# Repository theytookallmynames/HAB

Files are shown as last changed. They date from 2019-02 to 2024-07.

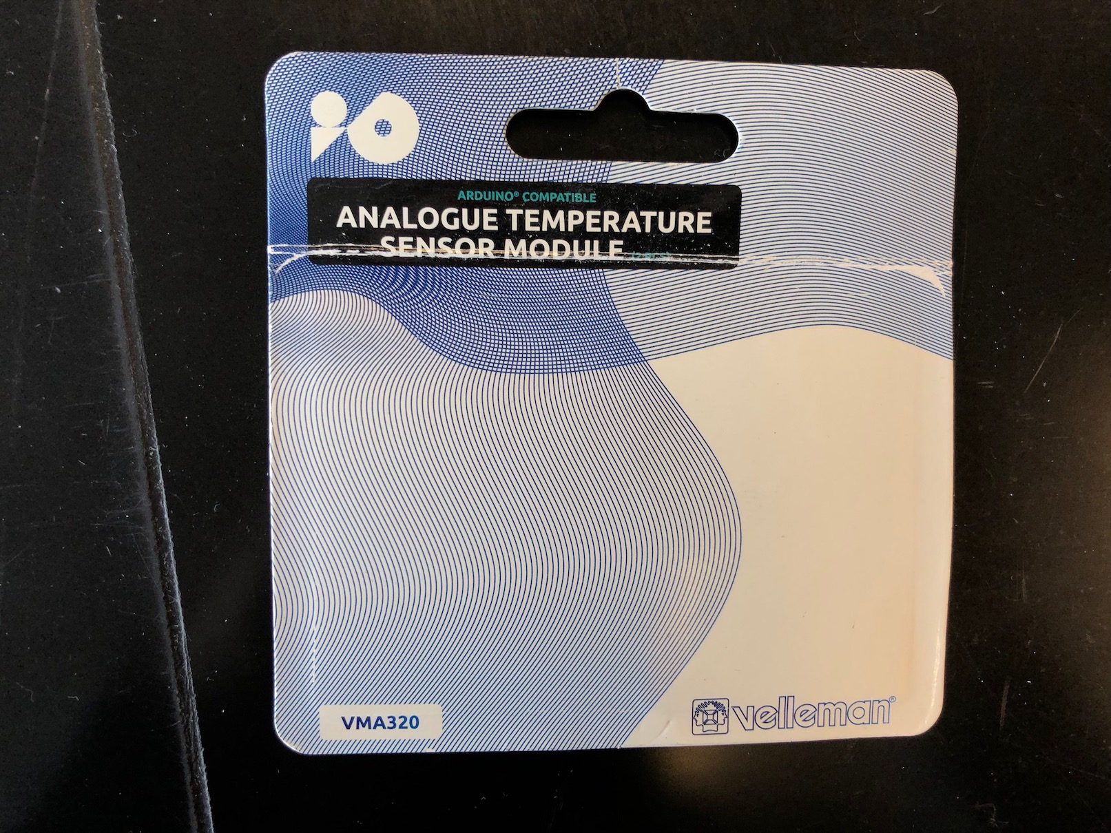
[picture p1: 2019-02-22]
docs/datasheets/temp sensors/thermistor package front.jpeg

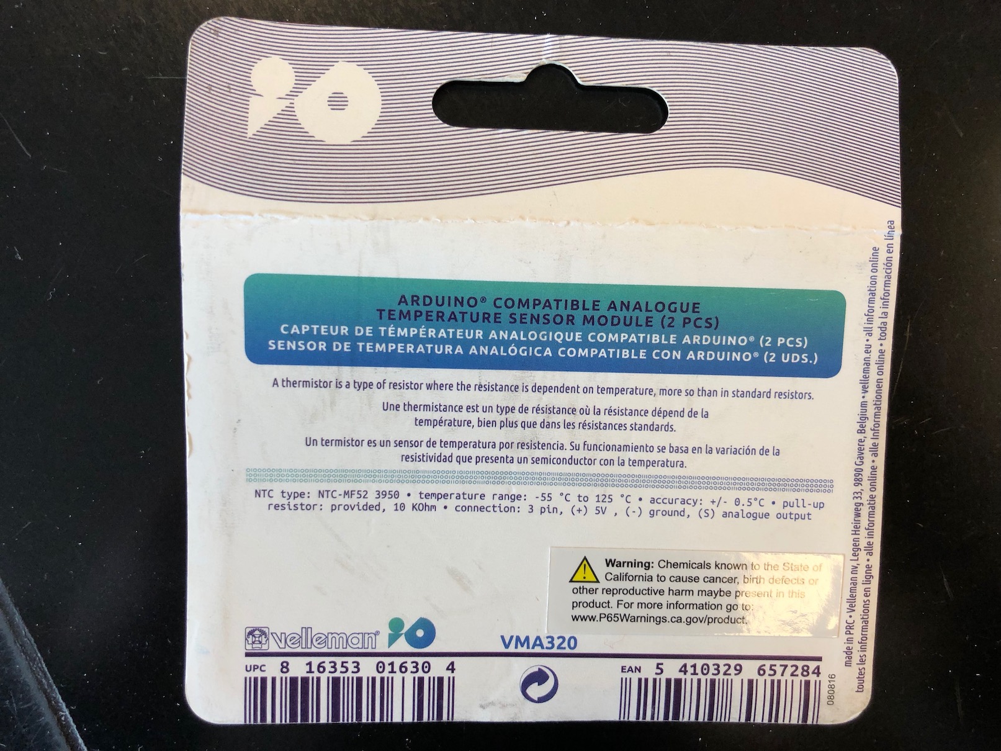
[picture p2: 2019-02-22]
docs/datasheets/temp sensors/thermistor package rear.jpeg

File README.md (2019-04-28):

# HAB
High altitude balloon project for Bergen's 2018 STEM program

## Setting up your development environment

1. Clone this repo.
2. Install the Arduino IDE: https://www.arduino.cc/en/main/software
3. Open the `HAB` directory in the repo in the IDE
4. Follow [these instructions](https://learn.adafruit.com/adafruit-feather-32u4-basic-proto/arduino-ide-setup) to install the "Adafruit AVR Boards" package in the IDE, and then set the board for the sketch to "Adafruit Feather M0" under the Tools > Boards menu.

You may need to install some additional libraries. To do that, go to the Tools menu in the Arduino IDE, search for the missing libraries, and hit the install button.

## Building the code

In the Arduino IDE, hit the checkmark button at the top of the window (or select Verify/Compile in the Sketch menu). This will make sure the code compiles correctly and will give some information at the bottom of the screen such as how much storage the compiled binary will take up on the device, and how much dynamic memory will be available for the program after global variables are taken into account.

## Installing on the arduino

In the Arduino IDE, press the button with the arrow (next to the button with the checkmark). If the code verifies properly, it will get uploaded to the Arduino and the Arduino will restart with the new code.

## Hardware

See the docs folder for datasheets.

### Board

Adafruit Feather M0 Adalogger

https://learn.adafruit.com/adafruit-feather-m0-adalogger/overview

### Sensors

#### Temperature sensor

Velleman VMA320 analog temperature sensor module

#### Pressure sensor

Honeywell HSCRNN1.6BA2A3

#### GPS receiver

Byonics GPS5HAOEM module
NaviSys GM-401 SiRFstarIV chip

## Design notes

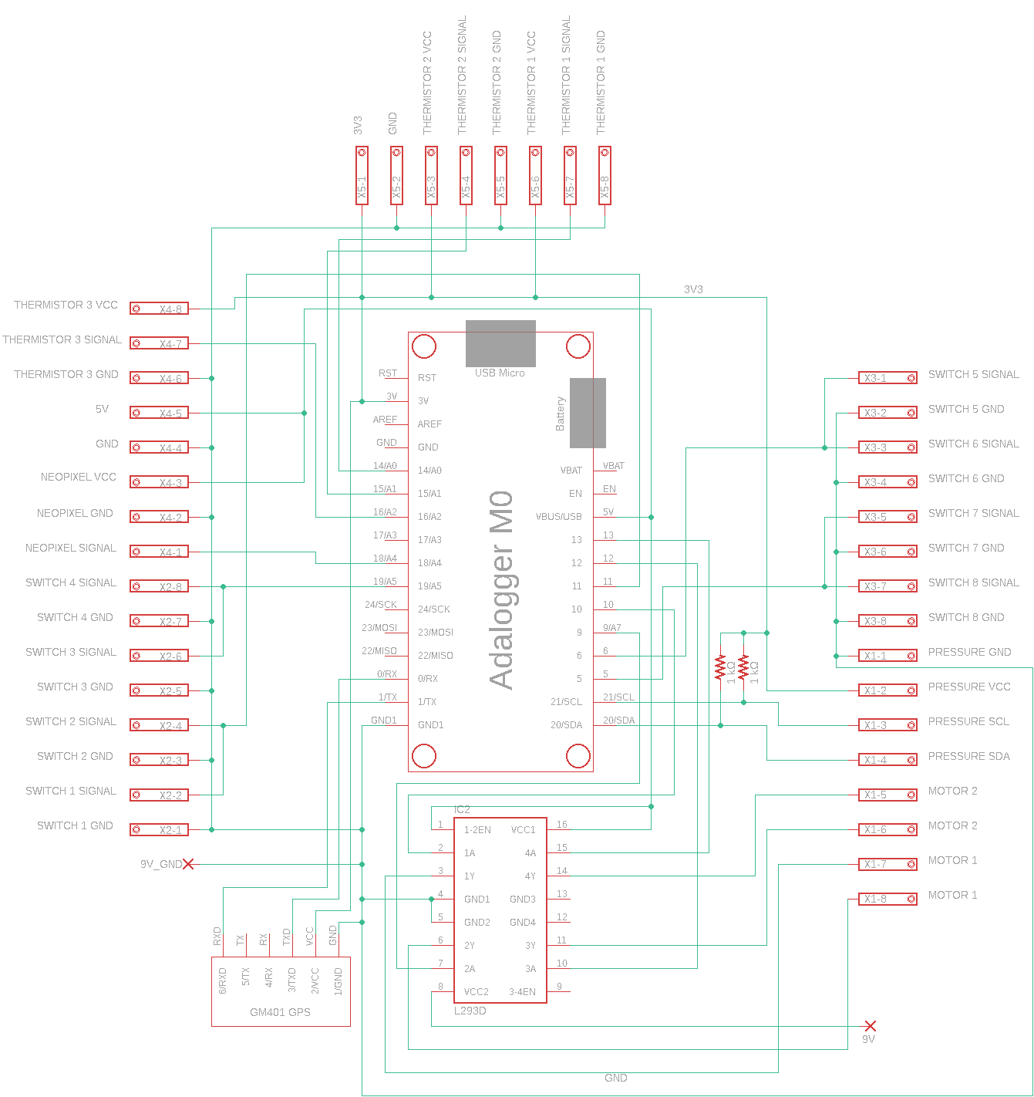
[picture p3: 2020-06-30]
docs/schematic v4.png

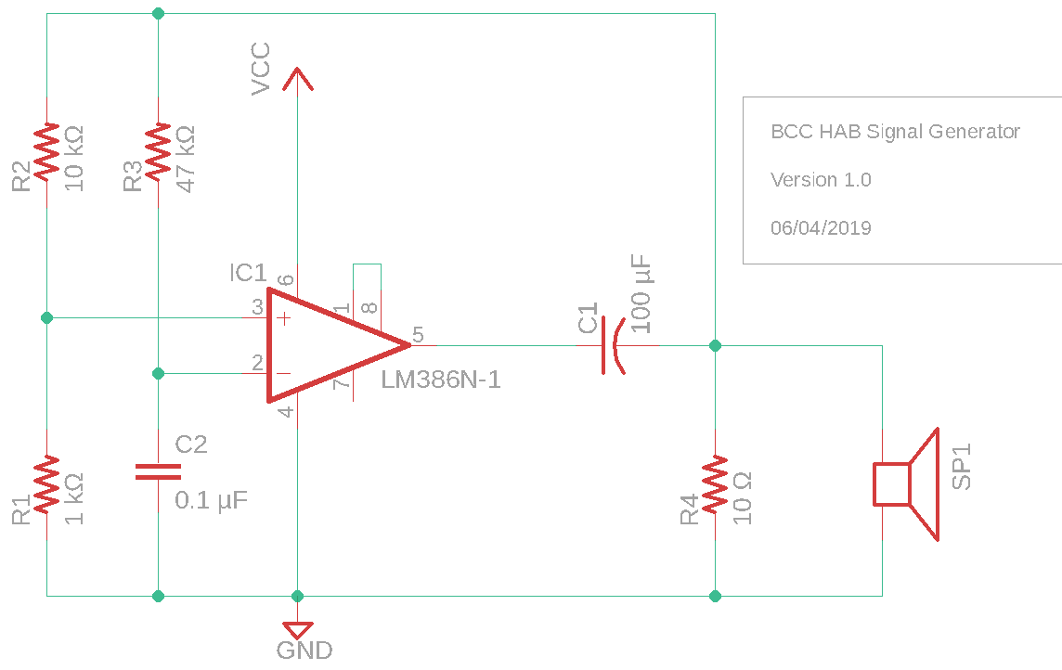
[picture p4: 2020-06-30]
docs/tone generator schematic v1.png

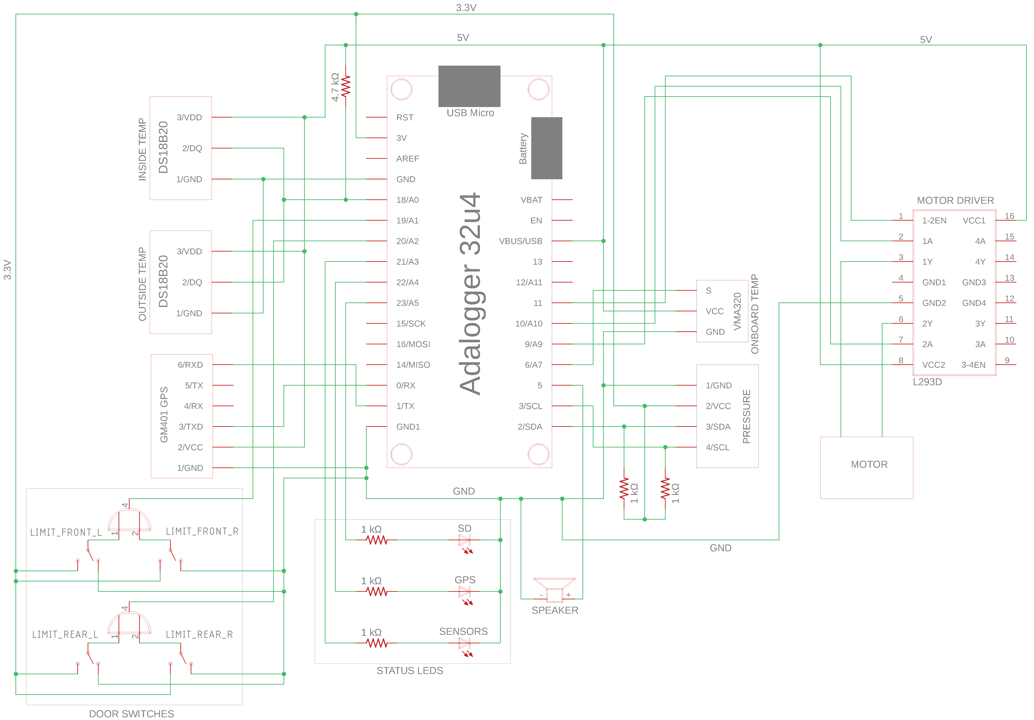
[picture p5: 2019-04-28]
docs/schematic v1.png

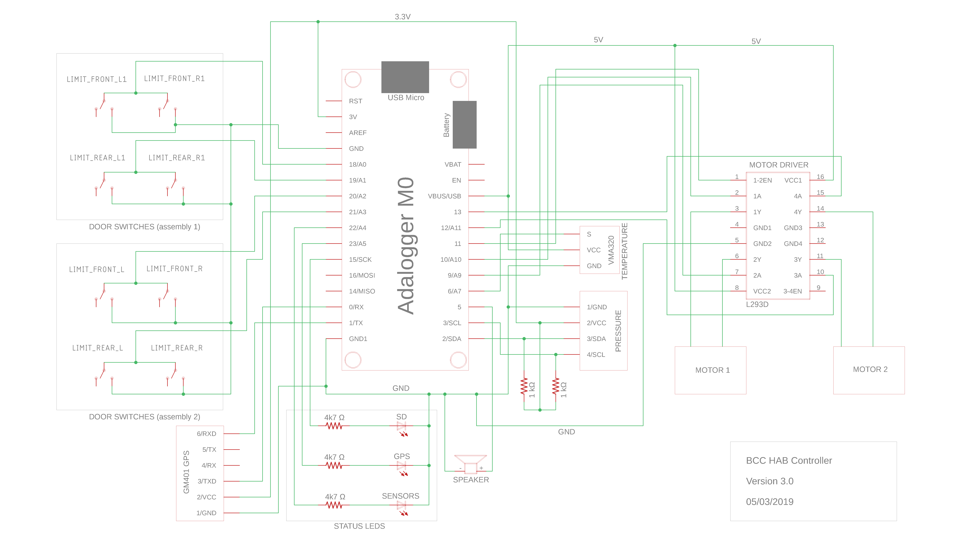
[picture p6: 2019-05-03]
docs/schematic v3.png

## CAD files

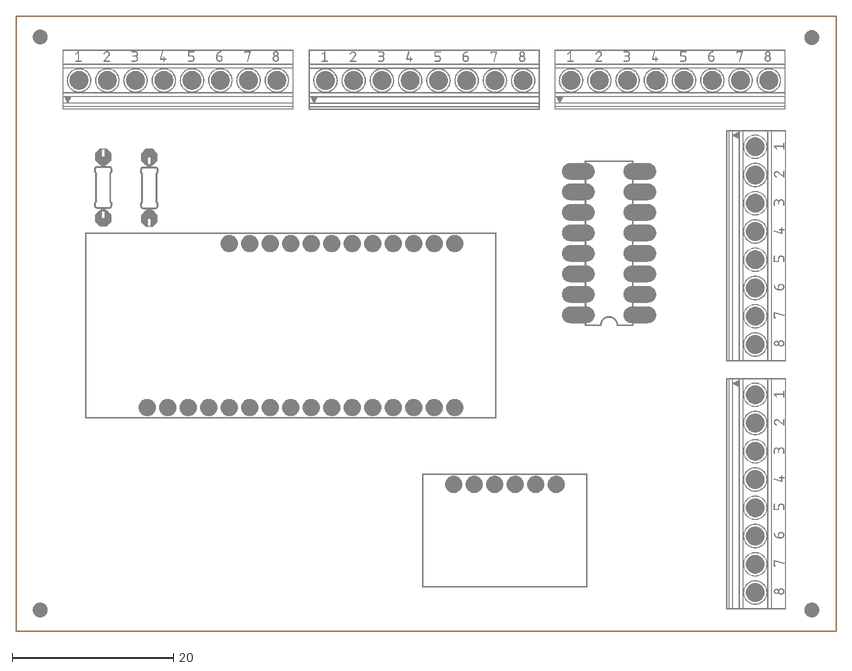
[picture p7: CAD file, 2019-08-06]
electronics/terminals.dxf
101.6 x 76.2

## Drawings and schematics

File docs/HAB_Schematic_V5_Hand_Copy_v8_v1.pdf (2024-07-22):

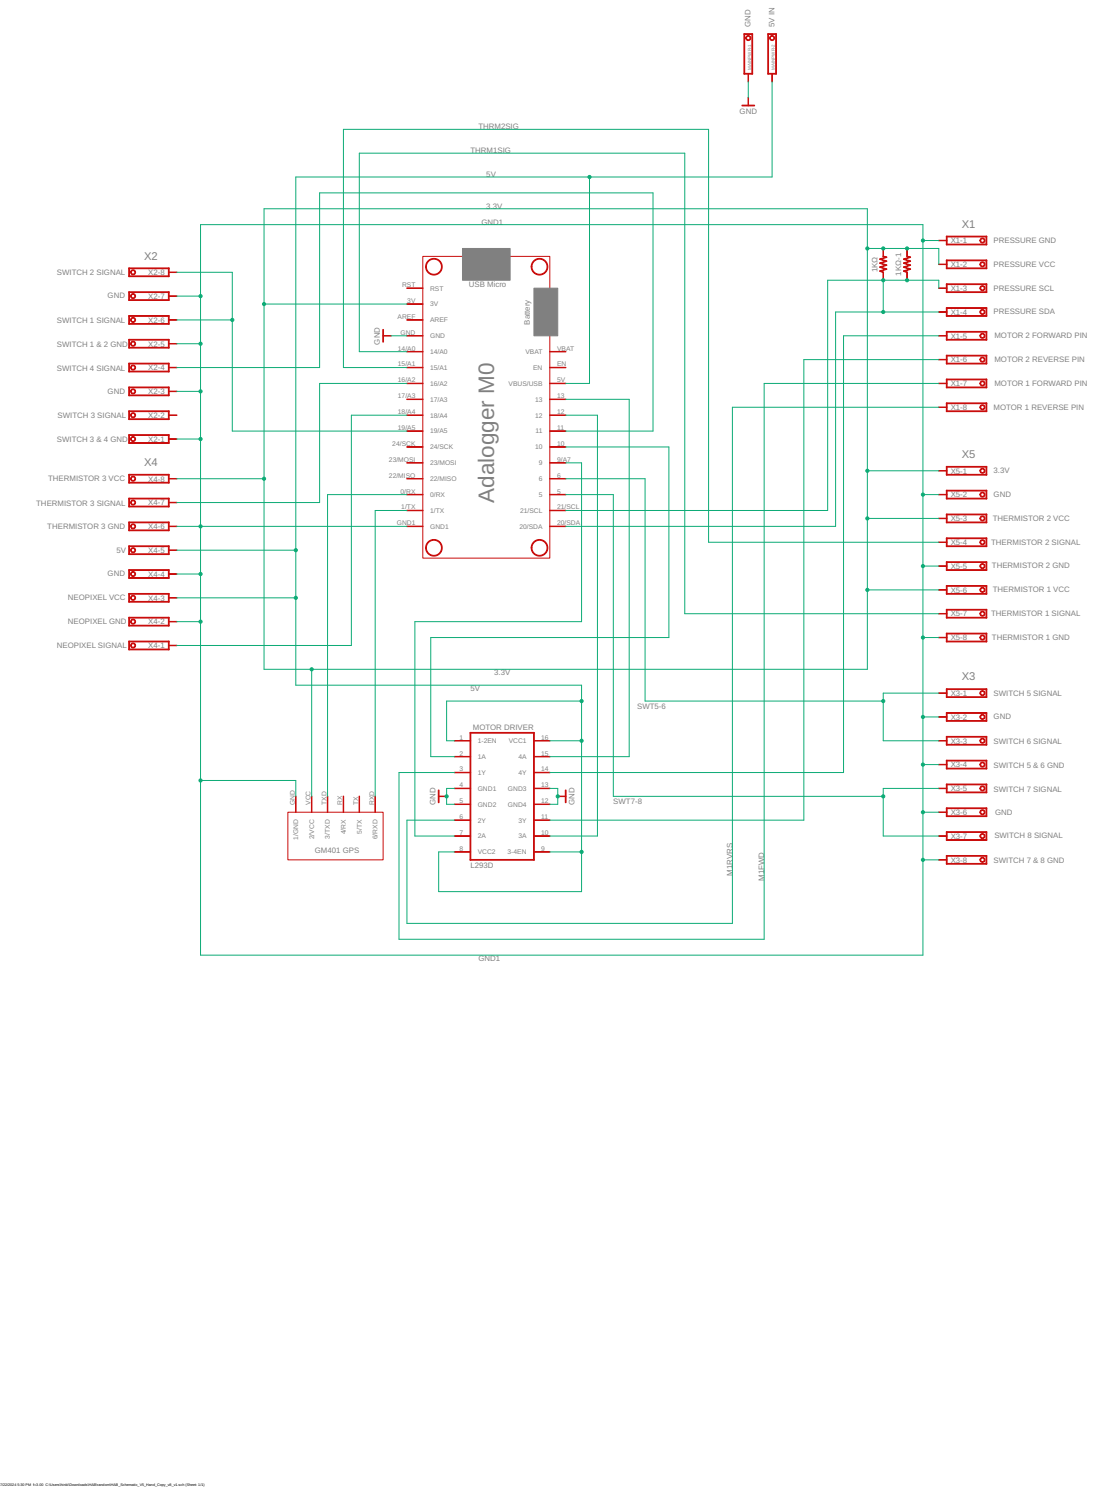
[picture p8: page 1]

GND1

7/22/2024 5:30 PM f=3.00 C:\Users\hinki\Downloads\HAB\random\HAB_Schematic_V5_Hand_Copy_v8_v1.sch (Sheet: 1/1)

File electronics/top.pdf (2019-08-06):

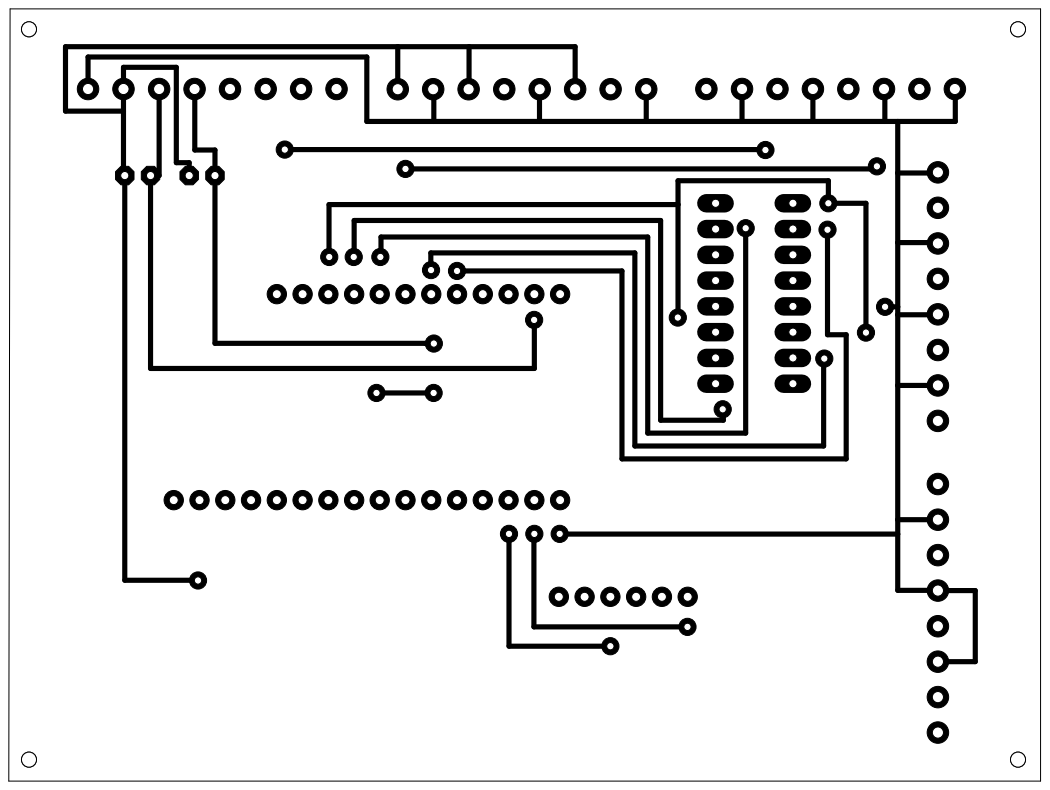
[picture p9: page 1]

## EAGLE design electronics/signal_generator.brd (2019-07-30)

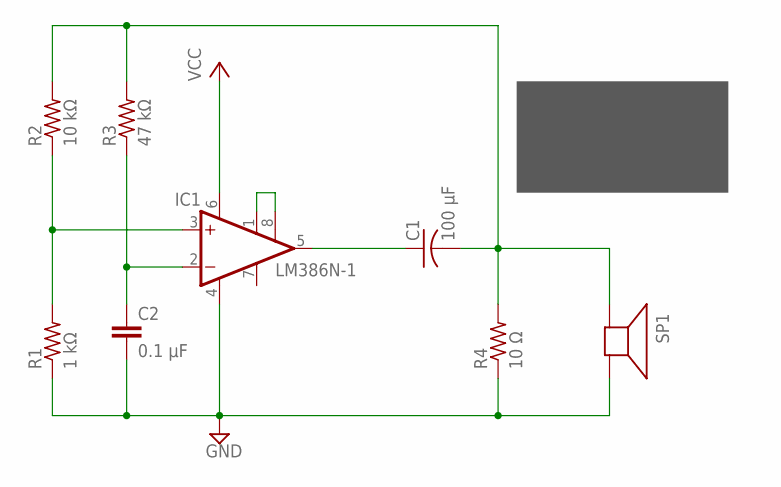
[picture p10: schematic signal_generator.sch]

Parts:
C1: 100 µF; C025-024X044
C2: 0.1 µF; C2.5-3
IC1: LM386N-1; DIL08
R1: 1 kΩ; 0204/7
R2: 10 kΩ; 0204/7
R3: 47 kΩ; 0204/7
R4: 10 Ω; 0204/7
SP1: SPEAKER/AL60P; AL60P

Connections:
GND: C2.2, IC1.4 (GND), R1.1, R4.1, SP1.2 (-)
OUT: C1.2, R2.2, R3.2, R4.2, SP1.1 (+)
PIN1-8: IC1.1 (GAIN), IC1.8 (GAIN)
PIN2: C2.1, IC1.2 (-IN), R3.1
PIN3: IC1.3 (+IN), R1.2, R2.1
PIN5: C1.1, IC1.5 (OUT)
VCC: IC1.6 (VS)

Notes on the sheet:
BCC HAB Signal Generator Version 1.0 06/04/2019

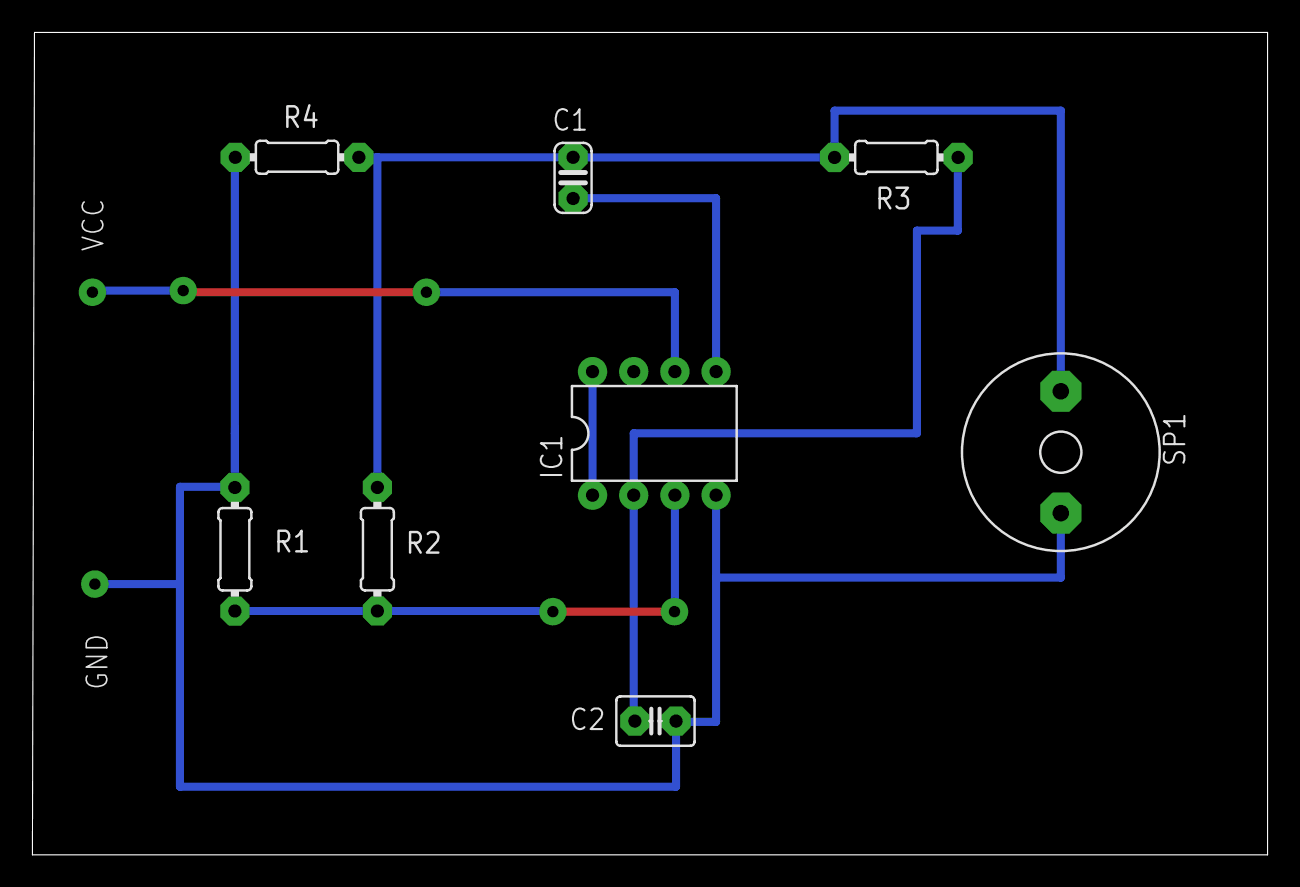
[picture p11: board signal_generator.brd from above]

Board: 2 copper layers, 76.2 x 50.7 mm, 8 parts (0 on the bottom side), 6 nets.

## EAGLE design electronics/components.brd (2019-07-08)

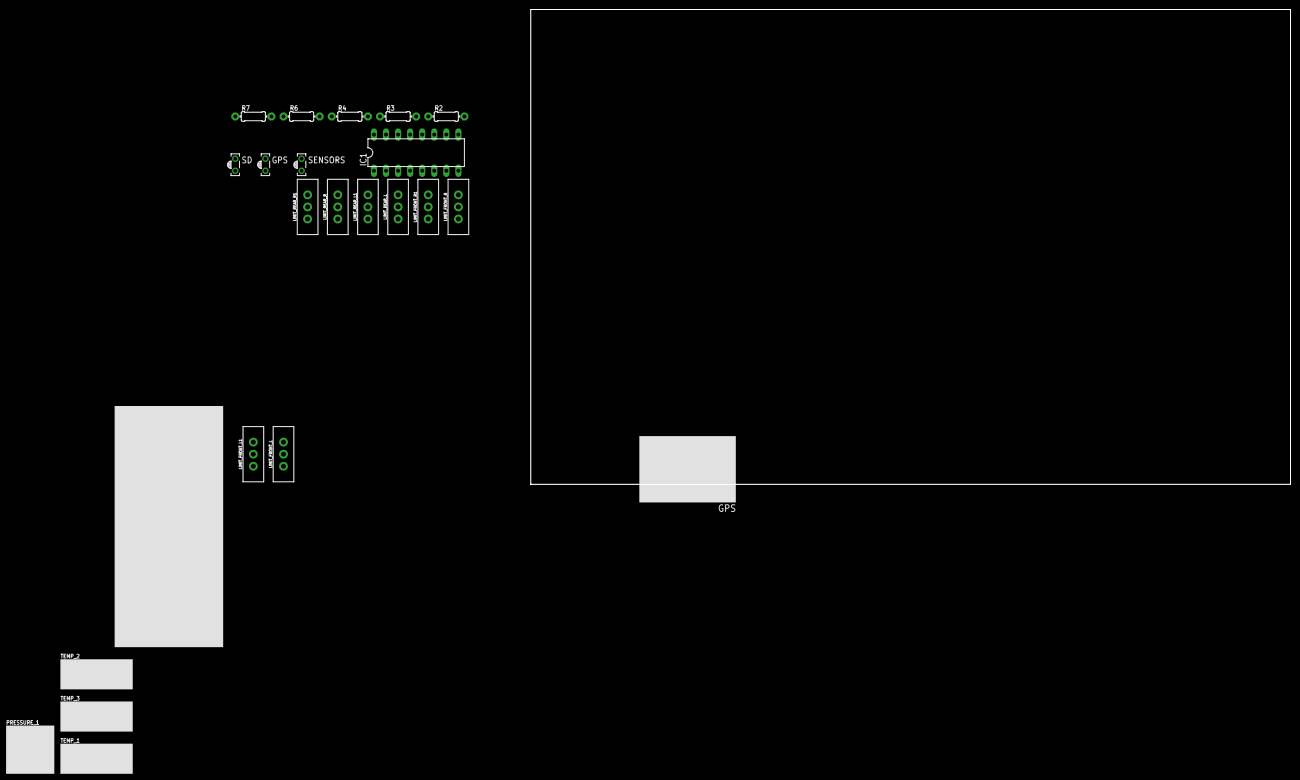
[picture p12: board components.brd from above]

Board: 2 copper layers, 160.0 x 100.0 mm, 23 parts (0 on the bottom side), 26 nets, no tracks yet.

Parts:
GPS: IRL80A
IC1: L293D; DIL16
LIMIT_FRONT_L, LIMIT_FRONT_L1: SWITCH_SPDT_PTH_11.6X4.0MM
LIMIT_FRONT_R, LIMIT_FRONT_R1: SWITCH_SPDT_PTH_11.6X4.0MM
LIMIT_REAR_L, LIMIT_REAR_L1: SWITCH_SPDT_PTH_11.6X4.0MM
LIMIT_REAR_R, LIMIT_REAR_R1: SWITCH_SPDT_PTH_11.6X4.0MM
PRESSURE_1: PRESSURE; HSC_PRESSURE
R2, R3, R4: 4k7 Ω; 0204/7
R6, R7: 1 kΩ; 0204/7
SD: IRL80A
SENSORS: IRL80A
TEMP_1, TEMP_2, TEMP_3: VMA320
U$1: ADALOGGER_M0; BOARD
U$3: GPS; GPS_BREAKOUT

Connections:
3.3V: PRESSURE_1.VCC, R6.1, R7.1, TEMP_1.VCC, TEMP_2.VCC, TEMP_3.VCC, U$1.3V, U$3.VCC
5V: IC1.1, IC1.8, IC1.16, U$1.5V
GND: IC1.5, LIMIT_FRONT_L.3, LIMIT_FRONT_L1.3, LIMIT_FRONT_R.3, LIMIT_FRONT_R1.3, LIMIT_REAR_L.3, LIMIT_REAR_L1.3, LIMIT_REAR_R.3, LIMIT_REAR_R1.3, PRESSURE_1.GND, U$1.GND1, U$3.GND
unnamed: TEMP_1.GND, TEMP_2.GND, TEMP_3.GND, U$1.GND
unnamed: U$1.0/RX, U$3.TXD
unnamed: TEMP_2.S, U$1.14/A0
unnamed: U$1.1/TX, U$3.RXD
unnamed: IC1.2, U$1.10
unnamed: PRESSURE_1.SDA, R6.2, U$1.20/SDA
unnamed: PRESSURE_1.SCL, R7.2, U$1.21/SCL
unnamed: TEMP_1.S, U$1.16/A2
unnamed: R4.2, SENSORS.A
unnamed: GPS.A, R3.2
unnamed: R2.2, SD.A
unnamed: IC1.7, U$1.9/A7
unnamed: LIMIT_REAR_L.2, LIMIT_REAR_R.2, U$1.5
unnamed: TEMP_3.S, U$1.15/A1
unnamed: IC1.10, U$1.12
unnamed: GPS.K, SD.K, SENSORS.K
unnamed: IC1.15, U$1.13
unnamed: LIMIT_FRONT_L1.2, LIMIT_FRONT_R1.2, U$1.11
unnamed: R4.1, U$1.22/MISO
unnamed: LIMIT_REAR_L1.2, LIMIT_REAR_R1.2, U$1.19/A5
unnamed: LIMIT_FRONT_L.2, LIMIT_FRONT_R.2, U$1.6
unnamed: R3.1, U$1.23/MOSI
unnamed: R2.1, U$1.24/SCK

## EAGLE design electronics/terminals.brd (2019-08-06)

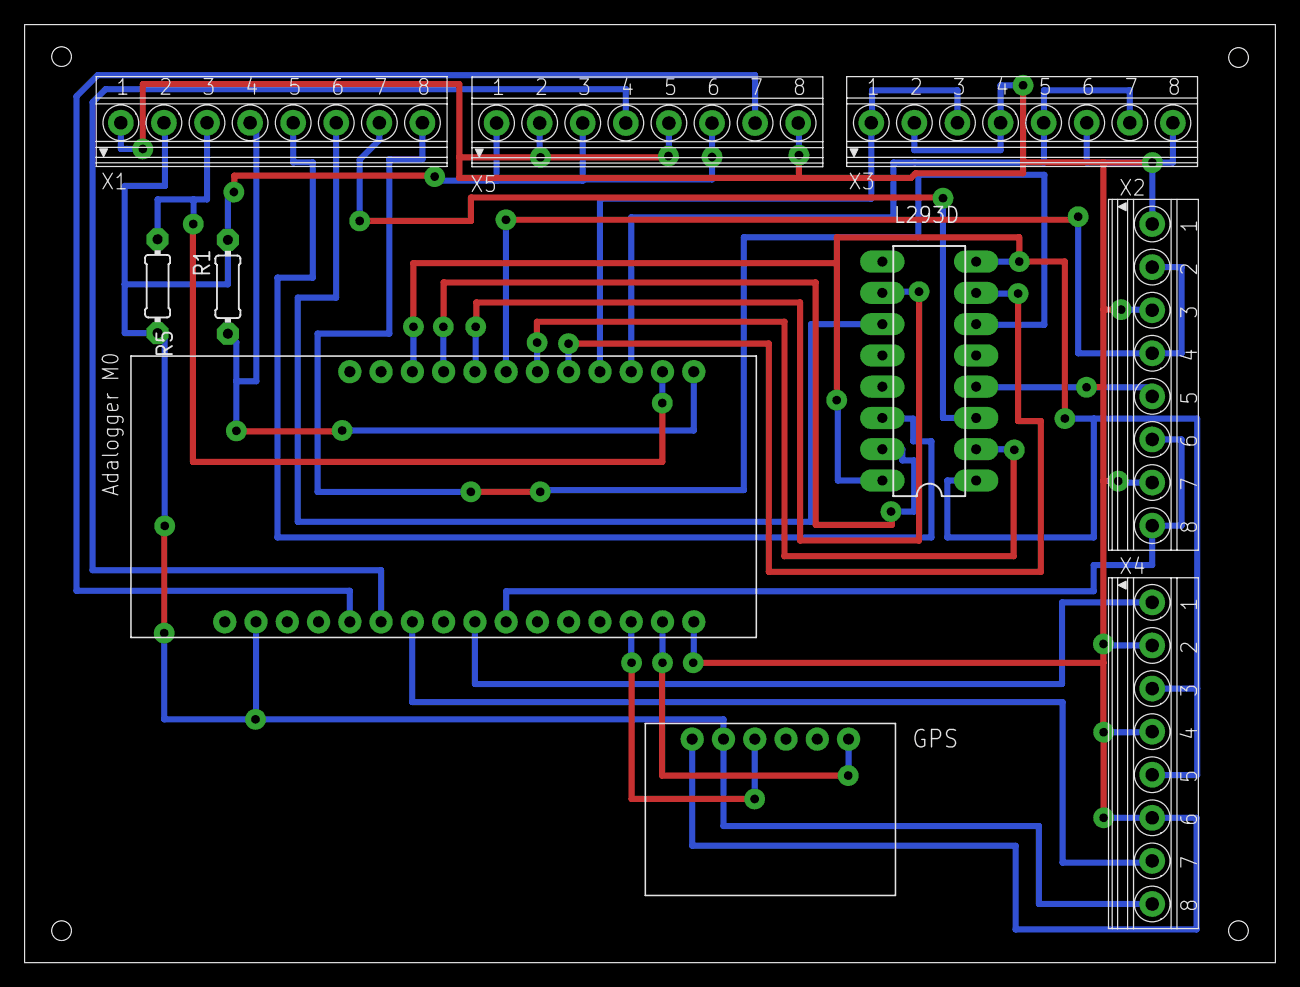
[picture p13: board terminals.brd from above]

Board: 2 copper layers, 101.6 x 76.2 mm, 10 parts (0 on the bottom side), 23 nets.

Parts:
IC2: L293D; DIL16
M0: Adalogger M0; BOARD
R1, R5: 1 kΩ; 0204/7
U$1: GPS; GPS_BREAKOUT
X1, X2, X3, X4, X5: 1751303

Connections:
3V3: M0.3V, R1.2, R5.2, U$1.VCC, X1.2, X4.8, X5.1, X5.3, X5.6
5V: IC2.1, IC2.8, IC2.16, M0.5V, X4.3, X4.5
GND: IC2.4, M0.GND1, U$1.GND, X1.1, X2.1, X2.3, X2.5, X2.7, X3.2, X3.4, X3.6, X3.8, X4.2, X4.4, X4.6, X5.2, X5.5, X5.8
GPS_RX: M0.1/TX, U$1.RXD
GPS_TX: M0.0/RX, U$1.TXD
L293_1A: IC2.2, M0.10
L293_2A: IC2.7, M0.9/A7
MOTOR_1_NEG: IC2.6, X1.8
MOTOR_1_POS: IC2.3, X1.7
MOTOR_2_NEG: IC2.11, X1.6
MOTOR_2_POS: IC2.14, X1.5
unnamed: IC2.15, M0.13
unnamed: IC2.10, M0.12
NEOPIXEL_SIG: M0.18/A4, X4.1
SCL: M0.21/SCL, R5.1, X1.3
SDA: M0.20/SDA, R1.1, X1.4
SW_1_2_SIG: M0.11, X2.2, X2.4
SW_3_4_SIG: M0.19/A5, X2.6, X2.8
SW_5_6_SIG: M0.6, X3.1, X3.3
SW_7_8_SIG: M0.5, X3.5, X3.7
THERM_1_SIG: M0.14/A0, X5.7
THERM_2_SIG: M0.15/A1, X5.4
THERM_3_SIG: M0.16/A2, X4.7

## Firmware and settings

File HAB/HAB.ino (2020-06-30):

#include "HAB.h"
#include "HAB_GPS.h"
#include "HAB_Logging.h"
#include "HAB_Sensors.h"
#include "HAB_Thermistor.h"
#include "HAB_Door.h"
#include "HAB_LED.h"
using namespace HAB;

void setup() {
  Serial.begin(9600);

  /**
   * Door initialization is accomplished by visual inspection of the doors opening and closing.
   */
  Door::init();

// Block until the serial monitor is connected in development
#ifdef HAB_DEVELOPMENT
  while(!Serial);
#endif

  Logging::logSystemData("System startup");

  LED::init();
  bool gpsInitSuccess = GPS::init();
  bool loggingInitSuccess = Logging::init();
  bool sensorInitSuccess = Sensors::init();
  /**
   * Door initialization is accomplished by visual inspection of the doors opening and closing.
   */
  Door::init();

  if (!gpsInitSuccess || !loggingInitSuccess || !sensorInitSuccess) {
    Logging::logSystemData("A subsystem failed to initialize properly. Aborting.");
    LED::statusLED(SYSTEM_STATUS_LED, LED::failure);
    return;
  }

  Logging::logSystemData("All subsystems initialized, starting main loop.");
  LED::statusLED(SYSTEM_STATUS_LED, LED::success);
}

void loop() {
  GPS::GPSData gpsData = GPS::process();
  
  Door::DoorStatus door1Status = Door::getDoorStatus1();
  Door::DoorStatus door2Status = Door::getDoorStatus2();

  Sensors::TemperatureData onboardTemperature = Sensors::onboardThermistor.getTemperature();
  Sensors::TemperatureData outdoorTopTemperature = Sensors::outdoorTopThermistor.getTemperature();
  Sensors::TemperatureData outdoorBottomTemperature = Sensors::outdoorBottomThermistor.getTemperature();
  Sensors::PressureData pressure = Sensors::getPressureData();

  Logging::MissionData data;
    
  data.setOnboardTemperature(onboardTemperature);
  data.setOutdoorTopTemperature(outdoorTopTemperature);
  data.setOutdoorBottomTemperature(outdoorBottomTemperature);
  data.setPressureData(pressure);
  data.setDoor1Status(door1Status);
  data.setDoor2Status(door2Status);
  data.setGpsData(gpsData);

  Logging::logMissionData(data.toString());

  if (gpsData.isValid) {
    adjustDoorIfNeeded(gpsData.altitude);
  }

  Logging::logSystemData(gpsData.nmeaSentence);

//  delay(1000);
}

//Doors opening and closing at 60000 ft
void adjustDoorIfNeeded(long altitude) {
  if (altitude >= MOTOR_OPEN_TRIGGER_ALTITUDE) {
      Door::openDoor();
      
      //TODO: System log the door opening time and altitude
  } else if (altitude <= MOTOR_CLOSE_TRIGGER_ALTITUDE) {
      Door::closeDoor();
      //TODO: System log the door closing time stamp and altitude
  }
}

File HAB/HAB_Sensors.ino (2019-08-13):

#include <Wire.h>
#include <math.h>
#include "HAB.h"
#include "HAB_Sensors.h"
#include "HAB_Thermistor.h"
#include "HAB_Logging.h"
#include "HAB_LED.h"

namespace HAB {
namespace Sensors {

bool initPressureSensors();
bool initThermistors();

bool init() {
 Logging::logSystemData("Initializing sensors now...");
 bool success = initPressureSensors() && initThermistors();
 return success;
}

/**
 * Initialize the pressure sensors.
 */
bool initPressureSensors() {
  Logging::logSystemData("Initializing Pressure Sensors...");
  LED::statusLED(PRESSURE_SENSOR_STATUS_LED, LED::pending);
  Wire.begin();
  delay(500);

  PressureData initialPressure = getPressureData();
  if (initialPressure.bar <= 0.0) {
    Logging::logSystemData(
      "Pressure sensor initialization failed: got pressure lower than 0 (" +
      String(initialPressure.bar) +
      " bar)"
    );
    LED::statusLED(PRESSURE_SENSOR_STATUS_LED, LED::failure);
    return false;
  }

  Logging::logSystemData(
    "Pressure sensors initialized. Initial pressure: " +
    String(initialPressure.bar) +
    " bar"
  );
  LED::statusLED(PRESSURE_SENSOR_STATUS_LED, LED::success);

  return true;
}

/**
 * Temperature initialization consists of
 */
bool initThermistors() {
  LED::statusLED(ONBOARD_TEMPERATURE_STATUS_LED, LED::pending);
  LED::statusLED(OUTDOOR_TOP_TEMPERATURE_STATUS_LED, LED::pending);
  LED::statusLED(OUTDOOR_BOTTOM_TEMPERATURE_STATUS_LED, LED::pending);

  TemperatureData onboardTemperature = onboardThermistor.getTemperature();
  TemperatureData outdoorTopTemperature = outdoorTopThermistor.getTemperature();
  TemperatureData outdoorBottomTemperature = outdoorBottomThermistor.getTemperature();

  if (onboardTemperature.tempC <= 0.0) {
    Logging::logSystemData(
      "Onboard temperature sensor initialization failed: got temperature lower than 0 (" +
      String(onboardTemperature.tempC) +
      " C)"
    );

    LED::statusLED(ONBOARD_TEMPERATURE_STATUS_LED, LED::failure);
    return false;
  } else {
    Logging::logSystemData(
      "Onboard temperature sensor initialized. Initial temperature: " +
      String(onboardTemperature.tempC) +
      "C"
    );
    LED::statusLED(ONBOARD_TEMPERATURE_STATUS_LED, LED::success);
  }

  if (outdoorTopTemperature.tempC <= 0.0) {
    Logging::logSystemData(
      "Outdoor top temperature sensor initialization failed: got temperature lower than 0 (" +
      String(outdoorTopTemperature.tempC) +
      " C)");

     LED::statusLED(OUTDOOR_TOP_TEMPERATURE_STATUS_LED, LED::failure);
     return false;
  } else {
    Logging::logSystemData(
      "Outdoor top temperature sensor initialized. Initial temperature: " +
      String(outdoorTopTemperature.tempC) +
      "C"
    );
    LED::statusLED(OUTDOOR_TOP_TEMPERATURE_STATUS_LED, LED::success);
  }

  if (outdoorBottomTemperature.tempC <= 0.0) {
    Logging::logSystemData(
      "Outdoor bottom temperature sensor initialization failed: got temperature lower than 0 (" +
      String(outdoorBottomTemperature.tempC) +
      " C)"
    );
    LED::statusLED(OUTDOOR_BOTTOM_TEMPERATURE_STATUS_LED, LED::failure);
    return false;
  } else {
    Logging::logSystemData(
      "Outdoor bottom temperature sensor initialized. Initial temperature: " +
      String(outdoorBottomTemperature.tempC) +
      "C"
    );
    LED::statusLED(OUTDOOR_BOTTOM_TEMPERATURE_STATUS_LED, LED::success);
  }

  return true;
}
/**
 * Convert the raw reading from the pressure sensor to a usable pressure in units of bars.
 * See page 2 of the Honeywell I2C Communication PDF for details on the data protocol,
 * and page 3 for the conversion formula.
 */
float rawPressureToBar(int raw) {
  float pressure = ((float)raw - PRESSURE_MIN_OUTPUT) * (PRESSURE_MAX_PRESSURE - PRESSURE_MIN_PRESSURE);
  pressure /= (PRESSURE_MAX_OUTPUT - PRESSURE_MIN_OUTPUT);
  pressure += PRESSURE_MIN_PRESSURE;

  return pressure;
}

/**
 * Get a reading from the pressure sensors. Returns a PressureData struct containing the
 * raw sensor data and the pressure in bar units.
 */
PressureData getPressureData() {
  PressureData data;

  // I'm not sure this is necessary, but it's in one of the Wire examples:
  // https://www.arduino.cc/en/Tutorial/SFRRangerReader
  Wire.beginTransmission(PRESSURE_I2C_ADDR);
  Wire.write(0);
  Wire.endTransmission();

  // Request two bytes from the pressure sensor
  Wire.requestFrom(PRESSURE_I2C_ADDR, 2);

  // Wait until two bytes are available from the sensor
  while (Wire.available() < 2);
  byte firstByte = Wire.read();
  byte secondByte = Wire.read();

  // https://github.com/AlexSatrapa/SSC/blob/819f06b4f4ce40cb438103ef416f8990c1536ea6/SSC.cpp#L37
  data.raw = (((int)(firstByte & 0x3f)) << 8) | secondByte;
  data.bar = rawPressureToBar(data.raw);

#ifdef HAB_DEVELOPMENT
  Serial.println("Pressure | raw: " + String(data.raw) + ", bar: " + String(data.bar));
#endif

  return data;
}

} // namespace Sensors
} // namespace HAB

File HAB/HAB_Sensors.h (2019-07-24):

#ifndef HAB_SENSORS_H
#define HAB_SENSORS_H
#include "HAB_Thermistor.h"

namespace HAB {
namespace Sensors {

Thermistor onboardThermistor = Thermistor(TEMPERATURE_ONBOARD_PIN);
Thermistor outdoorTopThermistor = Thermistor(TEMPERATURE_OUTDOOR_TOP_PIN);
Thermistor outdoorBottomThermistor = Thermistor(TEMPERATURE_OUTDOOR_BOTTOM_PIN);

/**
 * The I2C address for the pressure sensor. See Honeywell HSC PDF page 13 figure 4 (output type).
 */
#define PRESSURE_I2C_ADDR 0x28

/**
 * These values are used for converting the raw reading from the pressure sensor
 * to a usable value in units of bars.
 *
 * See page 3 of the Honeywell I2C communication PDF for the conversion formula.
 * 
 * Based on our pressure sensor type, its transfer function was 10% to 90% of 2^14 counts,
 * therefore pressure min output (10% of 2^14 counts) has to be set to 1638.0 and max output
 * to 90% of 2^14 counts (14746.0)
 */
 
#define PRESSURE_MIN_OUTPUT 1638.0 // Honeywell HSC PDF page 10 table 7
#define PRESSURE_MAX_OUTPUT 14746.0 // Honeywell HSC PDF page 10 table 7
#define PRESSURE_MIN_PRESSURE 0.0 // Honeywell HSC PDF page 13 figure 4
#define PRESSURE_MAX_PRESSURE 1.6 // Honeywell HSC PDF page 13 figure 4

struct PressureData {
  int raw;
  float bar;
};

bool init();
PressureData getPressureData();

} // namespace Sensors
} // namespace HAB

#endif // HAB_SENSORS_H

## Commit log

2018-08-15 motor tests pins
2018-08-16 temprature sensor and motors
2019-04-28 rewrite for better organization and new board and sensors
2019-05-03 add pin definitions for second payload
2019-05-20 Added Thermistor class
2019-05-20 Added thermistor pins
2019-05-20 Added temperature logging
2019-05-20 Removed temperature related code from Sensors
2019-05-28 - Removed Thermistor declaring/defining from HAB file and moved to Sensors. - Added pre-flight temperature sensors check. - All three thermistors work properly.
2019-06-05 Removed blinking LED code from GPS file
2019-06-13 Logging module updates and clean up:
    - Switched missionFile.read() to systemFile.read() in Logging.
    - Removed commented out old logic.
2019-06-13 Pins update:
    - changed pins for LEDs and Temperature sensors
2019-06-19 Removed GPS LEDs blinking
2019-06-20 Temp sensors, LEDs and switches pins update
2019-06-25 Initialize the door in the main loop Added in the Intermediate state to enum DoorStatus Fixed open and close door logic
    [HAB.ino, HAB_Door.ino]
2019-06-26 Created the HAB_LED.ino and HAB_LED.h files that uses the neopixel LED strip and replaces the three status LEDs we had.
    [HAB.h, HAB.ino, HAB_GPS.ino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]
2019-07-01 minor cleanup and formatting fixes
    [HAB.h, HAB.ino, HAB_Door.ino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]
2019-07-04 Logging and GPS changes:
    - Logging mission and system info logic is completed
    - Switched to NeoGPS library for getting GPS information
2019-07-08 Add eagle schematic files to repo
    [components.brd, components.sch, signal_generator.brd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]
2019-07-22 Logging Update
    - Updated logging procedure to not depend on GPS
    - Added milliseconds as a main timestamp
    - Successfully tested - logging of data continued with the loss of GPS signal
2019-07-24 Changed the pressure min output and pressure max output for more accurate pressure data.
2019-07-24 Added comment explaining pressure value changes.
2019-07-30 Fixed issue where the serial monitor was outputting that the doors were opened after they timed out.
    [HAB.ino, HAB_Door.ino]
2019-07-30 Add additional vias to the board layout
    Any traces that need to connect to the pins of an IC (arduino, GPS or
    motor driver) need to do so on the bottom layer. So any traces
    that are on the top layer need to be routed through a via to the
    bottom layer.
    [terminals.brd, terminals.sch]
2019-07-30 increase size of routes and pads
    [signal_generator.brd, signal_generator.sch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]
2019-08-06 move all traces except vias to bottom layer
    [terminals.brd, terminals.dxf, terminals.sch]
2019-08-07 Edited the code so that the status LED for the GPS will change to a failure state if the GPS loses a signal after 60 seconds.
    [HAB_GPS.ino]
2019-08-13 update GPS status LED after initialization
2019-08-15 Fixed pull request from vitosamson HAB repository for personal repository.
    [HAB.ino, HAB_GPS.ino]
2020-06-30 Added the latest schematic and added the schematic for the tone generator to the docs file.
2024-07-22 Add files via upload
    Copy of the Schematic from 2023 Summer.
    [HAB Schematic V5 Hand Copy.sch]

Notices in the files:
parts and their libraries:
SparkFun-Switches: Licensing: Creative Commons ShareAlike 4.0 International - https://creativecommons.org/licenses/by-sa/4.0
